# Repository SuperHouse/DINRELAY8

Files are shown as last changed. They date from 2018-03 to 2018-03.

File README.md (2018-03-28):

DIN-Mount 8-Channel Relay Output
================================
Copyright 2017-2018 SuperHouse Automation Pty Ltd  www.superhouse.tv  

8-channel relay board designed for switching mains loads in a
switchboard. Fits inside a H8456 DIN-rail mounted case.

Includes a switchmode power supply with 5V output. Controls for the
relays are provided on an I/O Breakout header (12-pin IDC) compatible
with other I/O Breakout boards from SuperHouse.

More information is available at:

  http://www.superhouse.tv/dinrelay8

INSTALLATION
------------
The design is saved as an EAGLE project. EAGLE PCB design software is
available from www.cadsoftusa.com free for non-commercial use. To use
this project download it and place the directory containing these files
into the "eagle" directory on your computer. Then open EAGLE and
navigate to the project.

DISTRIBUTION
------------
The specific terms of distribution of this project are governed by the
license referenced below.

LICENSE
-------
Licensed under the TAPR Open Hardware License (www.tapr.org/OHL).
The "license" folder within this repository also contains a copy of
this license in plain text format.

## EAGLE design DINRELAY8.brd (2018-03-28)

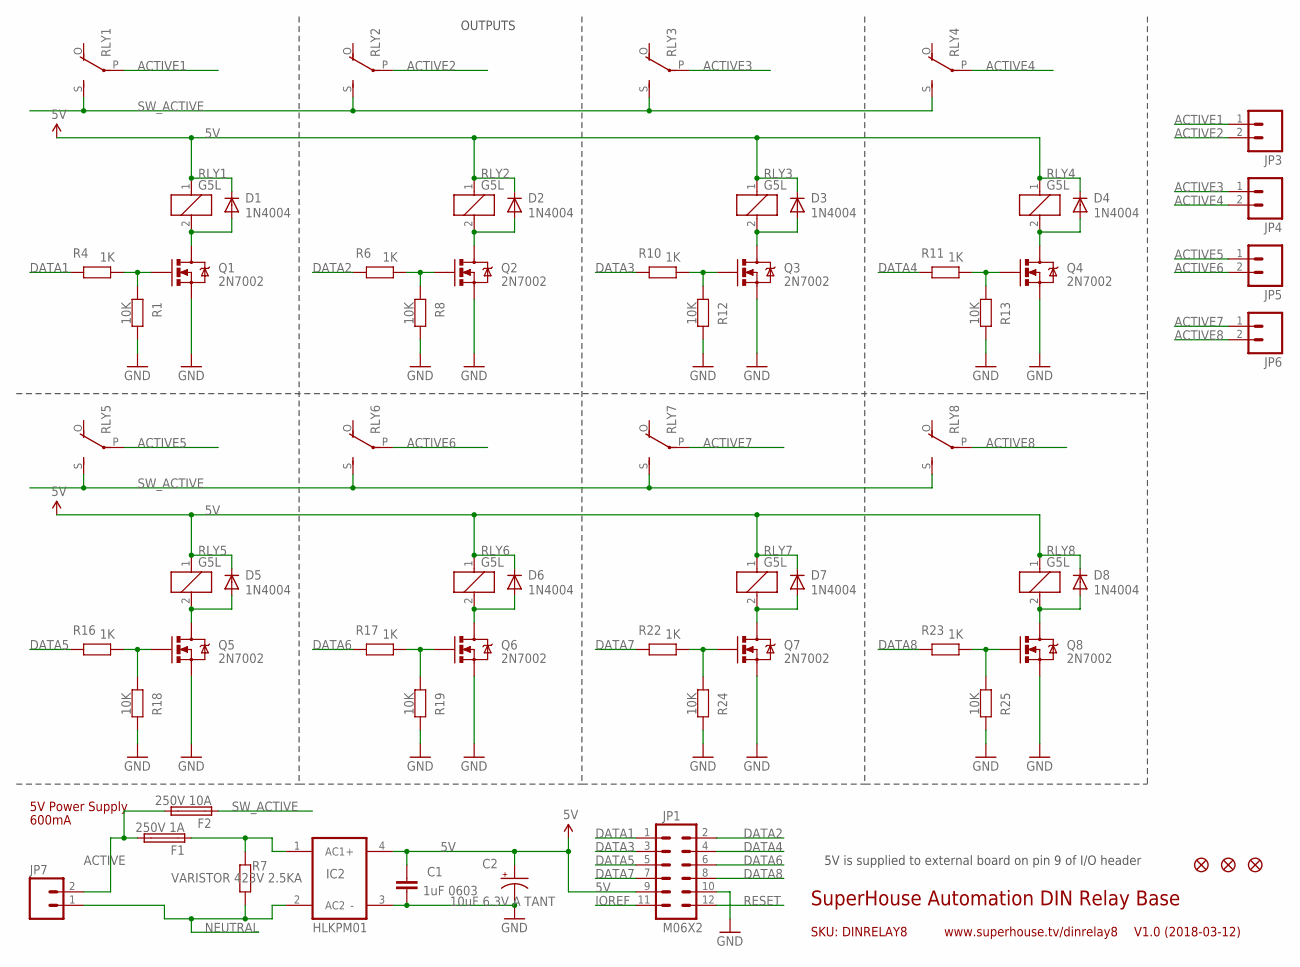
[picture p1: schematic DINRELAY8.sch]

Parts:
C1: 1uF 0603; 0603@1
C2: 10uF 6.3V A TANT; EIA3216
D1, D2, D3, D4, D5, D6, D7, D8: 1N4004; SMB-DIODE
F1: 250V 1A; PICOFUSE
F2: 250V 10A; PICOFUSE
FID1, FID2, FID3: FIDUCIAL1X2.5; FIDUCIAL-1X2.5
IC2: HLKPM01
JP1: M06X2; 2X6-SHROUDED
JP3, JP4, JP5, JP6, JP7: M025MM; SCREWTERMINAL-5MM-2
Q1, Q2, Q3, Q4, Q5, Q6, Q7, Q8: 2N7002; SOT23-3
R1, R8, R12, R13, R18, R19, R24, R25: 10K; 0603
R4, R6, R10, R11, R16, R17, R22, R23: 1K; 0603
R7: VARISTOR 423V 2.5KA; AXIAL-0.3
RLY1, RLY2, RLY3, RLY4, RLY5, RLY6, RLY7, RLY8: G5L; G5LE

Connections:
5V: C1.1, C2.A (+), D1.C, D2.C, D3.C, D4.C, D5.C, D6.C, D7.C, D8.C, IC2.4 (+), JP1.9, RLY1.1, RLY2.1, RLY3.1, RLY4.1, RLY5.1, RLY6.1, RLY7.1, RLY8.1
$N16: F1.1, IC2.1 (AC1), R7.P$2 (2)
ACTIVE: F1.2, F2.2, JP7.2
ACTIVE1: JP3.1, RLY1.P
ACTIVE2: JP3.2, RLY2.P
ACTIVE3: JP4.1, RLY3.P
ACTIVE4: JP4.2, RLY4.P
ACTIVE5: JP5.1, RLY5.P
ACTIVE6: JP5.2, RLY6.P
ACTIVE7: JP6.1, RLY7.P
ACTIVE8: JP6.2, RLY8.P
DATA1: JP1.1, R4.2
DATA2: JP1.2, R6.2
DATA3: JP1.3, R10.2
DATA4: JP1.4, R11.2
DATA5: JP1.5, R16.2
DATA6: JP1.6, R17.2
DATA7: JP1.7, R22.2
DATA8: JP1.8, R23.2
GND: C1.2, C2.C (-), IC2.3 (-), JP1.10, Q1.2 (S), Q2.2 (S), Q3.2 (S), Q4.2 (S), Q5.2 (S), Q6.2 (S), Q7.2 (S), Q8.2 (S), R1.2, R8.2, R12.2, R13.2, R18.2, R19.2, R24.2, R25.2
IOREF: JP1.11
unnamed: D2.A, Q2.3 (D), RLY2.2
unnamed: D1.A, Q1.3 (D), RLY1.2
unnamed: Q1.1 (G), R1.1, R4.1
unnamed: Q2.1 (G), R6.1, R8.1
unnamed: D4.A, Q4.3 (D), RLY4.2
unnamed: D3.A, Q3.3 (D), RLY3.2
unnamed: Q3.1 (G), R10.1, R12.1
unnamed: Q4.1 (G), R11.1, R13.1
unnamed: D6.A, Q6.3 (D), RLY6.2
unnamed: D5.A, Q5.3 (D), RLY5.2
unnamed: Q5.1 (G), R16.1, R18.1
unnamed: Q6.1 (G), R17.1, R19.1
unnamed: D8.A, Q8.3 (D), RLY8.2
unnamed: D7.A, Q7.3 (D), RLY7.2
unnamed: Q7.1 (G), R22.1, R24.1
unnamed: Q8.1 (G), R23.1, R25.1
NEUTRAL: IC2.2 (AC2), JP7.1, R7.P$1 (1)
RESET: JP1.12
SW_ACTIVE: F2.1, RLY1.S, RLY2.S, RLY3.S, RLY4.S, RLY5.S, RLY6.S, RLY7.S, RLY8.S

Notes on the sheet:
SKU: DINRELAY8
5V Power Supply
600mA
SuperHouse Automation DIN Relay Base
V1.0 (2018-03-12)
www.superhouse.tv/dinrelay8
OUTPUTS
5V is supplied to external board on pin 9 of I/O header

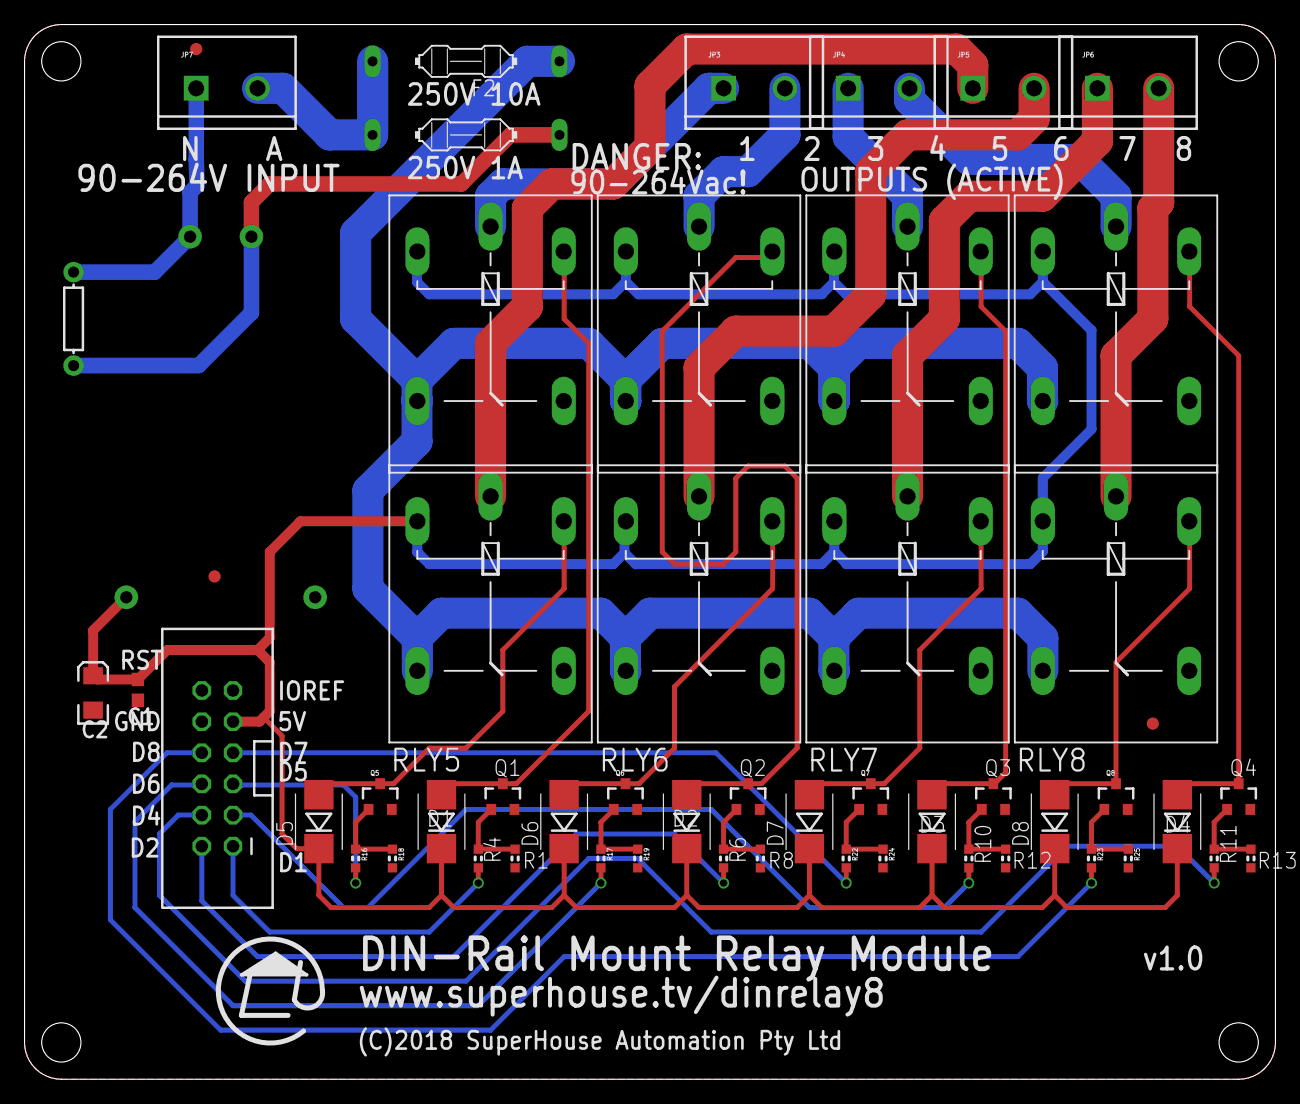
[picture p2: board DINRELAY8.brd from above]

Board: 2 copper layers, 102.0 x 86.0 mm, 55 parts (0 on the bottom side), 38 nets.

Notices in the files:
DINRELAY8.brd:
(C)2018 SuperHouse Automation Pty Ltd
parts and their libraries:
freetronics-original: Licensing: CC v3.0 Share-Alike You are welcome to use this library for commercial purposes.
